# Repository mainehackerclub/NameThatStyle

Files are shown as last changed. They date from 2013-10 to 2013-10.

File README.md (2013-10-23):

NameThatStyle
=============

For Name that Style Discovery Museum exhibit.

How to upload the program using Arduino IDE
===========================================
1. Add the following to the \arduino\hardware\arduino\boards.txt file (works for Arduino 1.0)

  ##############################################################

  atmega328smd16e.name=ATmega328 SMD (16Mhz Ext, no boot)

  atmega328smd16e.upload.protocol=stk500
  atmega328smd16e.upload.maximum_size=30720
  atmega328smd16e.upload.speed=57600

  atmega328smd16e.bootloader.low_fuses=0xFF
  atmega328smd16e.bootloader.high_fuses=0xDA
  atmega328smd16e.bootloader.extended_fuses=0x05
  atmega328smd16e.bootloader.path=arduino:atmega
  atmega328smd16e.bootloader.unlock_bits=0x3F
  atmega328smd16e.bootloader.lock_bits=0x0F

  atmega328smd16e.build.mcu=atmega328p
  atmega328smd16e.build.f_cpu=16000000L
  atmega328smd16e.build.core=arduino:arduino
  atmega328smd16e.build.variant=arduino:eightanaloginputs

  ##############################################################

  atmega328smd8i.name=ATmega328 SMD (8Mhz Int, no boot)

  atmega328smd8i.upload.protocol=stk500
  atmega328smd8i.upload.maximum_size=30720
  atmega328smd8i.upload.speed=57600

  atmega328smd8i.bootloader.low_fuses=0xE2
  atmega328smd8i.bootloader.high_fuses=0xD7
  atmega328smd8i.bootloader.extended_fuses=0x05
  atmega328smd8i.bootloader.unlock_bits=0x3F
  atmega328smd8i.bootloader.lock_bits=0x0F

  atmega328smd8i.build.mcu=atmega328p
  atmega328smd8i.build.f_cpu=8000000L
  atmega328smd8i.build.core=arduino:arduino
  atmega328smd8i.build.variant=arduino:eightanaloginputs

  ##############################################################

  atmega328smd1i.name=ATmega328 SMD (1Mhz Int, no boot)

  atmega328smd1i.upload.protocol=stk500
  atmega328smd1i.upload.maximum_size=30720
  atmega328smd1i.upload.speed=57600

  atmega328smd1i.bootloader.low_fuses=0x62
  atmega328smd1i.bootloader.high_fuses=0xD7
  atmega328smd1i.bootloader.extended_fuses=0x05
  atmega328smd1i.bootloader.unlock_bits=0x3F
  atmega328smd1i.bootloader.lock_bits=0x0F

  atmega328smd1i.build.mcu=atmega328p
  atmega328smd1i.build.f_cpu=1000000L
  atmega328smd1i.build.core=arduino:arduino
  atmega328smd1i.build.variant=arduino:eightanaloginputs

2. Restart Arduino IDE
3. Set the correct board Menu > Tools > Boards > ATmega328 SMD (8Mhz Int, no boot)
4. Select your programmer Menu > Tools > Programmer
5. Upload via Menu > File > Upload using programmer

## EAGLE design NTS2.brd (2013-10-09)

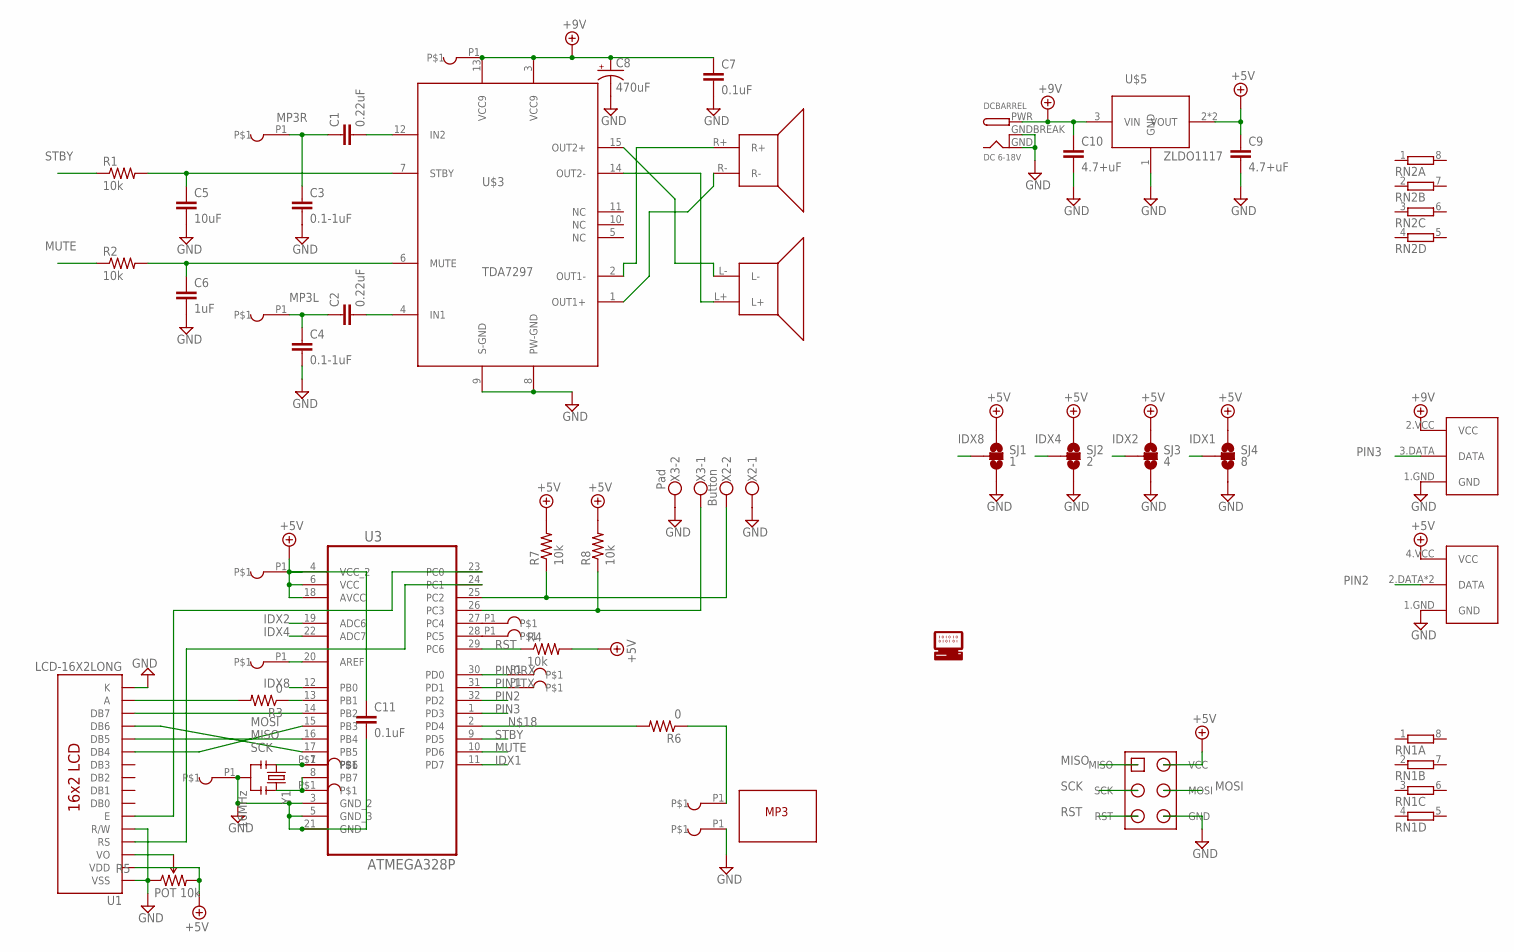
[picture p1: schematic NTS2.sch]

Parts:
AREF: AREF; JMP1
C1, C2: 0.22uF; 0805-XL
C3, C4: 0.1-1uF; 0805-XL
C5: 10uF; 0805-XL
C6: 1uF; 0805-XL
C7, C11: 0.1uF; 0805-XL
C8: 470uF; CAP-PTH-200-POL-HOR-R-600
C9: 4.7+uF; 1206
C10: 4.7+uF; 0805-XL
DCBARREL: DC 6-18V; DCJACK_2MM_PTH
GND: GND; JMP1
MP3+: M+; JMP1-RECT
MP3-: M-; JMP1-RECT
MP3-L: L; JMP1-RECT
MP3-R: R; JMP1-RECT
PB6: PB6; JMP1-SMD-100
PB7: PB7; JMP1-SMD-100
PC4: A4; JMP1
PC5: A5; JMP1
PD0: Rx; JMP1
PD1: Tx; JMP1
R1, R2, R4, R7, R8: 10k; 0805-XL
R3, R6: 0; 1206
R5: POT 10k; TRIM_POT_PTH
RN1: 4R-NCAT16; CAT16
RN2: 4R-N0402ARV341; 4X0402ARV341
SJ1: 1; SJ_2_BIN-PTH
SJ2: 2; SJ_2_BIN-PTH
SJ3: 4; SJ_2_BIN-PTH
SJ4: 8; SJ_2_BIN-PTH
U1: LCD-16X2LONG; LCD-16X2-LONG
U3: ATMEGA328P; QFP80P900X900X120-32N-LD
U$1: OUTLINE-MP3-MDM
U$2: HEAD-2X3-ISPISP6NLL; HEADER2X3-PTH-NOLABEL-LONG
U$3: TDA7297
U$4: SPEAKERSPTH; SPEAKER-5105
U$5: ZLDO1117; SOT223-3-L
U$6: RF-TRANSMITTER; RF-TRANSMIT
U$7: RF-RECEIVER
U$8: LOGO_HM512; LOGO_HM_512
VCC: VCC; JMP1
VIN: Vin; JMP1
X2: Button; CON-SCREW2
X3: Pad; CON-SCREW2
Y1: 16MHz; SMD-RESONATOR-320-130-PRQC

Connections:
+5V: C9.1, C11.1, R4.2, R5.3 (CW), R7.2, R8.2, SJ1.1, SJ2.1, SJ3.1, SJ4.1, U1.2 (VDD), U3.4 (VCC_2), U3.6 (VCC), U3.18 (AVCC), U$2.VCC, U$5.2 (VOUT), U$5.4 (VOUT), U$7.4.VCC (VCC), VCC.P1
+9V: C7.1, C8.2+ (+), C10.1, DCBARREL.PWR, U$3.3 (VCC9), U$3.13 (VCC9), U$5.3 (VIN), U$6.2.VCC (VCC), VIN.P1
AREF: AREF.P1, U3.20 (AREF)
GND: C3.2, C4.2, C5.2, C6.2, C7.2, C8.1- (-), C9.2, C10.2, C11.2, DCBARREL.GND, DCBARREL.GNDBREAK, GND.P1, MP3-.P1, R5.1 (CCW), SJ1.3, SJ2.3, SJ3.3, SJ4.3, U1.1 (VSS), U1.5 (R/W), U1.16 (K), U3.3 (GND_2), U3.5 (GND_3), U3.21 (GND), U$2.GND, U$3.8 (PW-GND), U$3.9 (S-GND), U$5.1 (GND), U$6.1.GND (GND), U$7.1.GND (GND), X2.1, X3.2, Y1.2.GND
IDX1: SJ4.2 (2.C), U3.11 (PD7)
IDX2: SJ3.2 (2.C), U3.19 (ADC6)
IDX4: SJ2.2 (2.C), U3.22 (ADC7)
IDX8: SJ1.2 (2.C), U3.12 (PB0)
MISO: U1.12 (DB5), U3.16 (PB4), U$2.MISO
MOSI: U1.11 (DB4), U3.15 (PB3), U$2.MOSI
MP3L: C2.1, C4.1, MP3-L.P1
MP3R: C1.1, C3.1, MP3-R.P1
MUTE: R2.1, U3.10 (PD6)
unnamed: U$3.15 (OUT2+), U$4.L-
unnamed: U$3.14 (OUT2-), U$4.L+
unnamed: U$3.2 (OUT1-), U$4.R+
unnamed: U$3.1 (OUT1+), U$4.R-
unnamed: R7.1, U3.25 (PC2), X2.2
unnamed: C1.2, U$3.12 (IN2)
unnamed: R8.1, U3.26 (PC3), X3.1
unnamed: C2.2, U$3.4 (IN1)
unnamed: C6.1, R2.2, U$3.6 (MUTE)
unnamed: C5.1, R1.2, U$3.7 (STBY)
unnamed: R3.1, U3.13 (PB1)
unnamed: U1.14 (DB7), U3.14 (PB2)
unnamed: PB6.P$1, U3.7 (PB6), Y1.1
unnamed: PB7.P$1, U3.8 (PB7), Y1.3
unnamed: R5.2 (WIPER), U1.3 (VO)
unnamed: U1.6 (E), U3.23 (PC0)
unnamed: U1.4 (RS), U3.24 (PC1)
unnamed: R6.2, U3.2 (PD4)
unnamed: R3.2, U1.15 (A)
unnamed: MP3+.P1, R6.1
unnamed: PC4.P1, U3.27 (PC4)
unnamed: PC5.P1, U3.28 (PC5)
PIN0RX: PD0.P1, U3.30 (PD0)
PIN1TX: PD1.P1, U3.31 (PD1)
PIN2: U3.32 (PD2), U$7.2.DATA (DATA), U$7.3.DATA (DATA)
PIN3: U3.1 (PD3), U$6.3.DATA (DATA)
RST: R4.1, U3.29 (PC6), U$2.RST
SCK: U1.13 (DB6), U3.17 (PB5), U$2.SCK
STBY: R1.1, U3.9 (PD5)

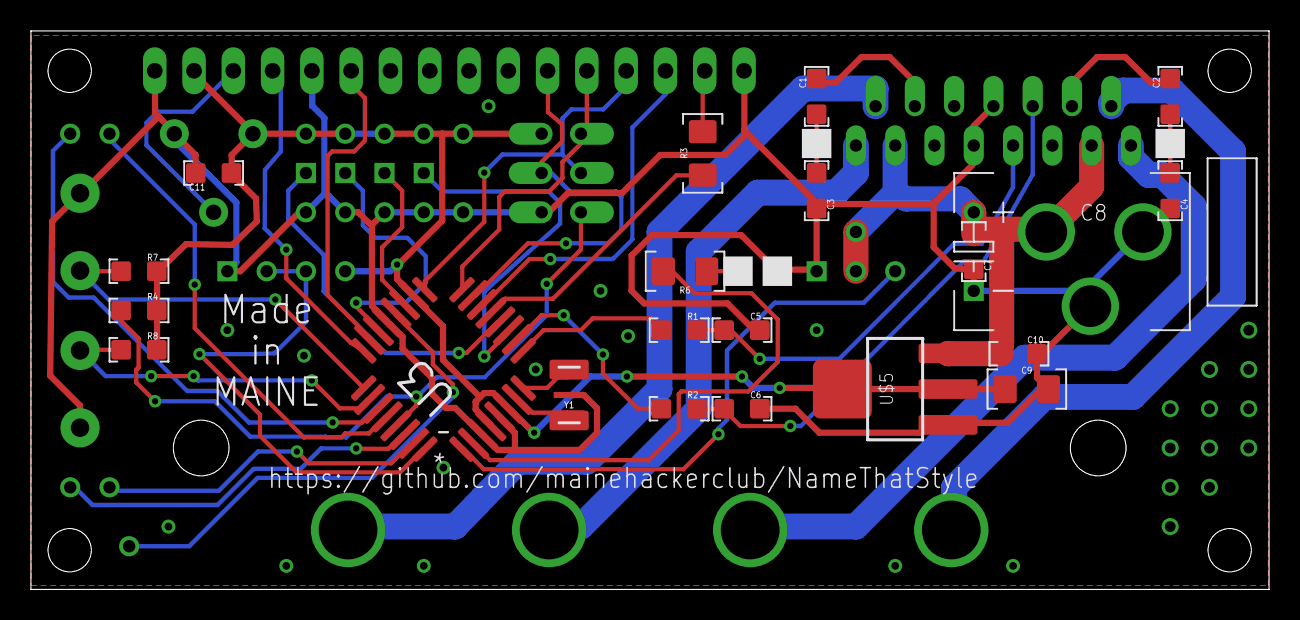
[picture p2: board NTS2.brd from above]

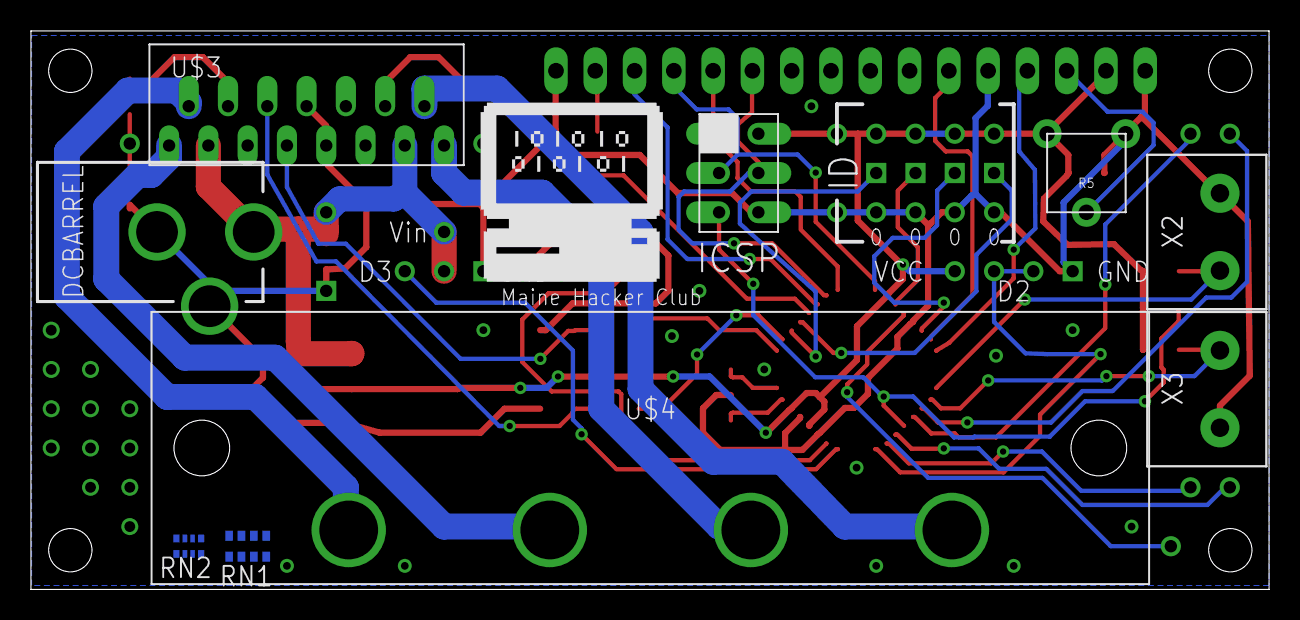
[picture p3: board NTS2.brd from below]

Board: 2 copper layers, 80.1 x 36.1 mm, 53 parts (16 on the bottom side), 42 nets.

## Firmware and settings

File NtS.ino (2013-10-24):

/*

  Name that Style
  
  amp datasheet: http://www.st.com/web/en/resource/technical/document/datasheet/CD00004985.pdf

 */


#include <LiquidCrystal.h>
#include "CButton.h"
#include "CLight.h"
#include "CMusic.h"
#include "CTimer.h"
#include "CProgressBar.h"
 
#define BLPIN 9 //backlight pin, must be PWM
#define PADPIN A3
#define BUTTONPIN A2
#define POWERPIN 4
#define STANDBYPIN 5
#define MUTEPIN 6

#define RS_PIN A1
#define E_PIN A0
#define D0_PIN 11
#define D1_PIN 12
#define D2_PIN 13
#define D3_PIN 10

#define PROGRESSBAR_CHAR_EMPTY 0
#define PROGRESSBAR_CHAR_FULL 1
#define PROGRESSBAR_CHAR_HALF 2
#define PROGRESSBAR_CHAR_LEFT 3
#define PROGRESSBAR_CHAR_RIGHT 4

#define SONG_NAME (song[DEV_ID].name)
#define SONG_DURATION (song[DEV_ID].length)

#define STATE_IDLE 0

LiquidCrystal lcd(RS_PIN, E_PIN, D0_PIN, D1_PIN, D2_PIN, D3_PIN);
CButton button(BUTTONPIN);
CButton pad(PADPIN);
CLight bl(BLPIN); //LCD Back Light
CMusic music(POWERPIN, STANDBYPIN, MUTEPIN);
CTimer dtimer; //timer for display messages
CTimer ptimer; //timer for the pad
CProgressBar progressBar; //display progress bar of the song


struct song_info_struct {
  long length; //song length in miliseconds
  String name; //song name to be displayed
} song[16] = {
   {10000, "-reserved-" }, //0
   {75000, "Blues" }, //1
   {42000, "Soul-Funk" }, //2
   {60000, "Hip-Hop" }, //3
   {60000, "Classical" }, //4
   {52000, "Jazz" }, //5
   {44000, "Country" }, //6
   {46000, "Spiritual/Gospel" }, //7
   {23000, "Rock&Roll" }, //8
   {100000, "Trance" }, //9
   {100000, "Trance" }, //10
   {100000, "Trance" }, //11
   {100000, "Trance" }, //12
   {100000, "Trance" }, //13
   {100000, "Trance" }, //14
   {100000, "Trance" }  //15
};

byte DEV_ID = 0;
byte state = STATE_IDLE;


/***************** EVENT HANDLERS *********************/


void onPadPush() {
//  ptimer.reset();
  bl.fadeOn();
  ptimer.setTimeout(1000, onPadPushTimer); //wait a second before doing anything in case somebody is just jumping on the pad
}

void onPadPushTimer() {
  if (!music.isPlaying()) {
    bl.fadeOn();
    lcd.clear();
    lcd.print("Starting...");
    music.play(SONG_DURATION); 
    lcd.clear();
    lcd.print("Playing");
  }
}

void onPadRelease() {
//  ptimer.reset();
  bl.fadeOff();
  ptimer.setTimeout(1000, onPadReleaseTimer); //wait a second before doing anything in case somebody is just jumping on the pad
}

void onPadReleaseTimer() {
  if (music.isPlaying()) {
    music.stop();
    bl.fadeOff();
    displayIdleScreen();
  }
}

void onButtonPress() {
  if (music.isPlaying()) {
    lcd.clear();
    lcd.print(SONG_NAME);
  }
}

void onSongFinish() {
  lcd.clear();
  lcd.print("Finished playing");
  lcd.print(SONG_NAME);
  bl.fadeOff();
  delay(1000);
  displayIdleScreen();
}

/********************** HELPERS *********************/

byte getDeviceID() {
  byte id = 0;
  if (digitalRead(8) > 0) id += 1;
  if (analogRead(A7) > 512) id += 2;
  if (analogRead(A6) > 512) id += 4;
  if (digitalRead(7) > 0) id += 8;
  return id;  
}

void displayIdleScreen() {
    lcd.clear();
    lcd.print("Name That Style");
    lcd.setCursor(0,1);
    lcd.print("Step on the pad");
}

/************************ SETUP ***********************/

void setup() {
  DEV_ID = getDeviceID();
    
  button.onKeyPress = onButtonPress;
  pad.onKeyDown = onPadPush;
  pad.onKeyUp = onPadRelease;
  music.onFinishPlay = onSongFinish;
  
  lcd.begin(16, 2);
  
  extern byte emptyBar[];
  extern byte halfBar[];
  extern byte fullBar[];
  extern byte leftBar[];
  extern byte rightBar[];
  
  lcd.createChar(PROGRESSBAR_CHAR_EMPTY, emptyBar);
  lcd.createChar(PROGRESSBAR_CHAR_HALF, halfBar);
  lcd.createChar(PROGRESSBAR_CHAR_FULL, fullBar);
  lcd.createChar(PROGRESSBAR_CHAR_LEFT, leftBar);
  lcd.createChar(PROGRESSBAR_CHAR_RIGHT, rightBar);
  progressBar.begin(&lcd, 1, 5, 15, PROGRESSBAR_CHAR_LEFT, PROGRESSBAR_CHAR_RIGHT, PROGRESSBAR_CHAR_EMPTY, PROGRESSBAR_CHAR_FULL, PROGRESSBAR_CHAR_HALF);
  progressBar.setRange(0, SONG_DURATION);
  
  bl.on();

  // display ID and song name
  lcd.clear();
  lcd.setCursor(0,0);
  lcd.print("ID:");
  lcd.print(DEV_ID);
  lcd.print(" L:");
  lcd.print(SONG_DURATION/1000);
  lcd.print("s");
  lcd.setCursor(0,1);
  lcd.print(SONG_NAME);
  delay(2000);
  bl.fadeOff();
  //lcd.clear();
  displayIdleScreen();
}

/*********************** LOOP ************************/

void loop() {
  button.update();
  pad.update();
  music.update();
  bl.update();
  ptimer.update();
  dtimer.update();
  if (music.isPlaying()) {
    long tpms = music.getTimePlaying();
    byte tpm = tpms / 60000;
    byte tps = (tpms % 60000) / 1000;
    lcd.setCursor(0,1);
    lcd.print(tpm);
    lcd.print(":");
    if (tps < 10) lcd.print("0");
    lcd.print(tps);
    lcd.print(" ");
    progressBar.update(tpms);
  }
  
  //lcd.print("     ");

}


//moo

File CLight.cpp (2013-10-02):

#include "CLight.h"


CLight::CLight(byte apin) : 
  pin(apin), 
  onFinishFade(NULL),
  currentPWM(0),
  goalPWM(0),
  isFading(0),
  lastFadeUpdate(0)
{
  pinMode(this->pin, OUTPUT);
}

void CLight::begin() {
  
}

void CLight::update() {
  if (this->isFading) {
    long time = millis();
    if (time > this->lastFadeUpdate + 10) {
      this->lastFadeUpdate = time;
      if (this->currentPWM == this->goalPWM) {
        this->isFading = 0;
        if (this->onFinishFade != NULL) this->onFinishFade();
      } else if (this->currentPWM > this->goalPWM) {
        this->currentPWM -= 5;
        analogWrite(this->pin, this->currentPWM);
      } else {
        this->currentPWM += 5;
        analogWrite(this->pin, this->currentPWM);
      }
    }
  }
}

void CLight::on() {
  this->currentPWM = 255;
  this->isFading = 0;
  digitalWrite(this->pin, HIGH);
}

void CLight::off() {
  this->currentPWM = 0;
  this->isFading = 0;
  digitalWrite(this->pin, LOW);
}

void CLight::fadeOn() {
  this->isFading = 1;
  this->goalPWM = 255;
}

void CLight::fadeOn(void (*aonFinishFade)()) {
  this->onFinishFade = aonFinishFade;
  this->fadeOn();
}

void CLight::fadeOff() {
  this->isFading = 1;
  this->goalPWM = 0;
}

void CLight::fadeOff(void (*aonFinishFade)()) {
  this->onFinishFade = aonFinishFade;
  this->fadeOff();
}

//moo
